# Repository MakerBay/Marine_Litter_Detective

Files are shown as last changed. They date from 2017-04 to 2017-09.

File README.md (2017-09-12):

# [Marine Litter Detective](http://marinelitterdetective.net/)

[Webpage Active now!](http://marinelitterdetective.net/)

http://marinelitterdetective.net/

Do you know where marine litter comes from?  A lot of litter generated on land actually ends up in the ocean, but how? WWF-Hong Kong, in cooperation with MakerBay, has designed a tracking device to simulate how litter enters the sea through storm drains and rivers, and is working with students from 11 schools to trace the journey of litter. This helps us understand the source of marine litter in Hong Kong and solve the problem together. If you find this device washed onto the shore, please pick it up and contact WWF (pyeung@wwf.org.hk) for collection. This project is sponsored by the Environment and Conservation Fund and the Environmental Campaign Committee of Hong Kong SAR Government.

wwf-logo-coconut

## Goal
Arduino in coconut
Map of Drifter in HK Waters

The goal of the Marine Litter Detective is to deploy more than a 100 GPS tracker devices to:
- Simulate the movement of trash from the land, into the drain system, into the river system, and into the sea of Hong Kong waters
- Create a map of coastal marine litter, to indicate where the trash comes from, where it goes, how quickly it travels, how frequently the same trash is observed on different beaches, how much of the trash goes in the ocean / gets stranded on the beach and more data
- Improve ocean current simulations and computer models
- Open hardware and software to enable more costal research and marine litter in the future

Our priorities are to make
- <b>reliable</b> GPS tracker fleets that give us frequent updates
- <b>environmentally friendly</b> casing (biodegradable)
- <b>low cost</b> 2G connected devices to operate in mobile phone range (good for coastal waters)
- devices which are <b>simple</b> to build so that over a hundred of students can build and deploy these sensors, collect data, analyse and share their findings

<hr>

## [Data visualisation](https://github.com/MakerBay/Trashtracker/tree/master/Dataviz)
Student Drifters

We have been very impressed with the work of Student Drifters, a research based program and we are learning a lot from them, principally about from their
- Python scripts and
- Leaflet-powered data visualisation: studentdrifters.org/huanxin/leaflet/examples/drifter.html .
We are  in the process of setting up a collaboration.

## [Software server side](https://github.com/MakerBay/Trashtracker/tree/master/Server)
Server

We are using a simple MySQL Server to collect the data via ftp/http request.
We are currently using a PHP script to extract the data and prepare it for data visualisation via a Json, or CSV file.

## [Software on device](https://github.com/MakerBay/Trashtracker/tree/master/Tracker)
Device

On the device we are using the Arduino IDE: https://www.arduino.cc/en/main/software

## [Electronics](https://github.com/MakerBay/Trashtracker/tree/master/Electronics)
Electonics

The devices are equipped with a 3.3V Arduino Pro Mini

## [Casing](https://github.com/MakerBay/Trashtracker/tree/master/Coconut)

We are trying to get our electronics as "eco" as possible, so the housing of our electronics is mainly composed of
- Wax / Paraffin: to make the electronics fully waterproof and float
- Tissue paper: to enhance the wax structure with the fibres to make it stronger

<hr>

## Credits
- [WWF-Hong Kong](https://wwf.org.hk)
- [MakerBay](https://www.makerbay.org)

## Team
- Patrick Yeung [WWF] +852 2161 9698, pyeung@wwf.org.hk
- Cesar Jung-Harada [MakerBay] +852 9610 7593, contact@cesarharada.com, https://github.com/cesarharada
- Eddie Yung [MakerBay] eddieyung2006@gmail.com, https://github.com/fisher4668
- Rohak Singhal [MakerBay] rohaksinghal14@gmail.com, https://github.com/krohak
- Jackie Wong Ching Sun [MakerBay] chinsun91@gmail.com, https://github.com/chinsun
- Michael CY CHENG [INDEPENDENT]

Special thanks to
- [Seeed Studio]( https://www.seeedstudio.com )
- [Student Drifter]( http://www.studentdrifters.org )
- Prof James Manning (NOAA) ( https://www.researchgate.net/profile/James_Manning3 )
- Xavier Huanxin Xu (NOAA)
- Tom Chi ( http://www.tomchi.com/ )
- Jie Qi (MIT) ( http://technolojie.com/category/featured-projects/ )
- Cy Keener (Stanford University) ( http://www.cykeener.com/ )
- Inspiration from https://www.greenwaveinstruments.com/product

<hr>

## Locations of launch
Classes Locations

11 Schools in Hong Kong all over the territory to launch at rivers and drains in 11 different areas
Totally 110 Devices will be deployed (10 devices per schools, 1 device per 2 to 3 students)

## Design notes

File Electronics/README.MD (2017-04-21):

# Bill of Materials
| Component | Quantity | Link |
| --- | --- | --- |
| Arduino Pro Mini 3.3V | 1 | https://goo.gl/s1k4pC |
| LoNet 808 Seeed (incl. GPS + Phone antenna) | 1 | https://goo.gl/HKax1F |
| Adapter board (custom made) | 1 | 
| Battery 18650 (2900mAh) | 1 | https://goo.gl/kCkjYg |
| Local Mobile SIM card | 1 | |
| Battery Wires, 15cm red and black | 1 | |
| Coconut shell from drinks | 1 | |
| Wax for Insulating electronics | 1 | |
| Cork chips | 1 | |
| Rubber Band from bicycle tyres | 1 | |
| "Dog Tag" in Aluminium with serial number and details to return device | 1 | https://goo.gl/YjCnZq |

This is how the different boards look like front and back

Gerber file Gerber file Gerber file Gerber file Gerber file

## Comments for manufacturing the kit with Seeed Studio
### LoNet 808
- LoNET 808 should come come with GPS and Phone antenna, does it?
- Header connector pins should be attached, can it be?
- LoNET 808 Power LED can be low power / skipped as it drains battery

Gerber file
### Comments for manufacturing PCBs
- PCBs to soldered
- PCBs to be Eco / Recycled PCBs / wood PCB

### Comments for sourcing batteries
- Battery 3000 mA/h, type: 18650, ideally Panasonic and cheap
- Can you make sure the batteries are 100% charged?
- Solder wires to the batteries (15cm) with connector mounted

### Comments for sourcing battery charger
- We need to charge 110 devices over 11 events. If we can charge 6 batteries at the time: great.

## Ask about
- Availabilites?
- Timeline?
- Bulk pricing?
- Overall budget?

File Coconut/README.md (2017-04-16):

# Find the coconut
supermarket coconut

# Drink the water
drink

# Cut it up
cut

# Eat the flesh
eat

# Chisel
chisel

# Prepare the electronics
elec

# Seal it
seal

# Launch the sensor
Launch the sensor

# Track your sensor
Track your sensor

# Research Notes 
## Biodegradable composite for casing
Biodegradable Material
Biodegradable Material
Moulded

In the process of developing the waterproofing of the electronics 

## Biodegradable electronics with paper and copper adhesive
Moulded

Above image is the courtesy of Jie Qi: https://www.flickr.com/photos/jieq/

Inspired by the work of Jie Qi we explored the possibility of making our own custom PCB out of paper and sticky copper. 
We hope to implement such eco-PCB soon. More research and tests coming soon :)

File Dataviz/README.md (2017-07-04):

This is the folder for Data Visualization

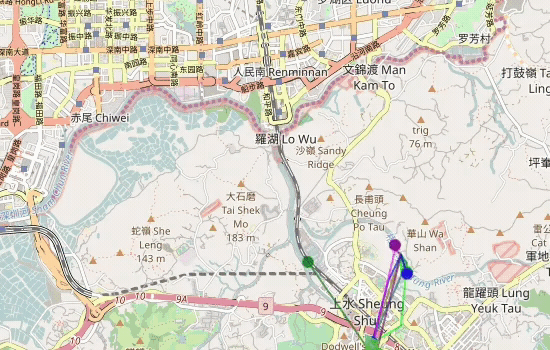
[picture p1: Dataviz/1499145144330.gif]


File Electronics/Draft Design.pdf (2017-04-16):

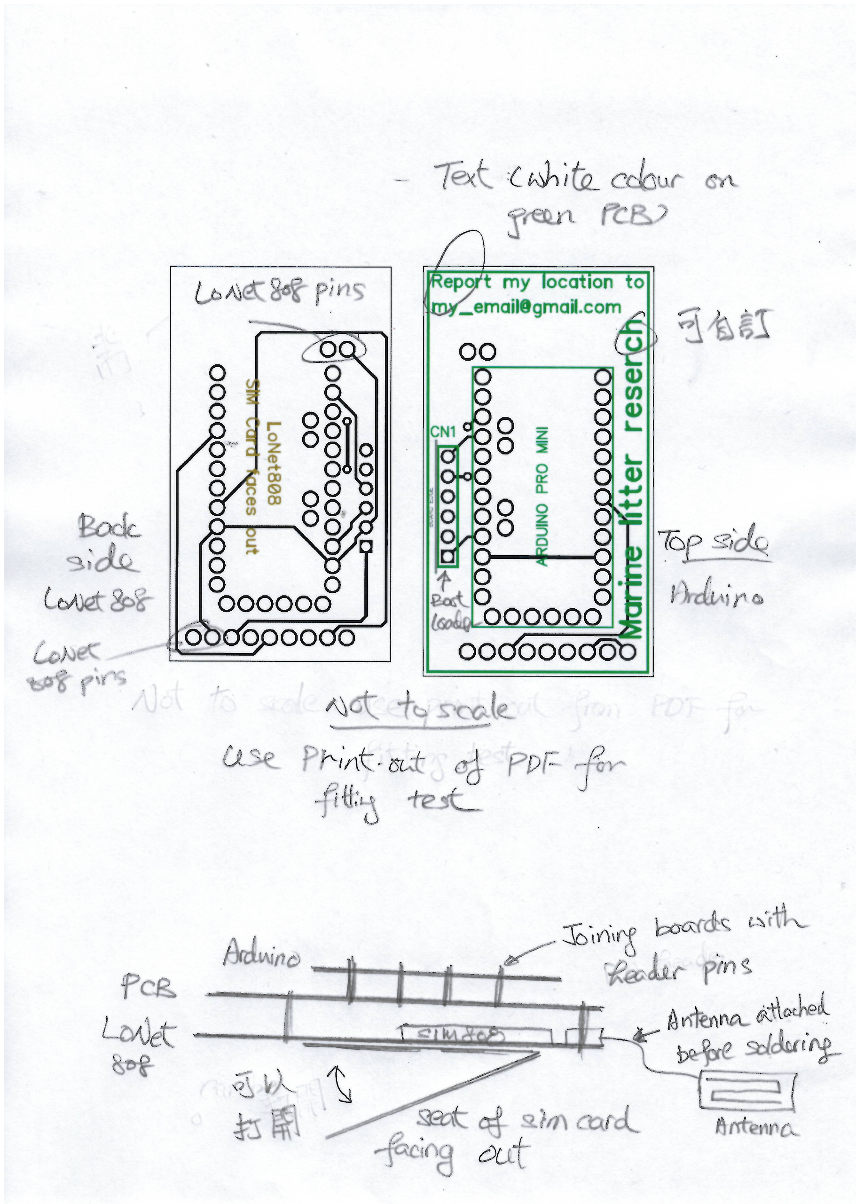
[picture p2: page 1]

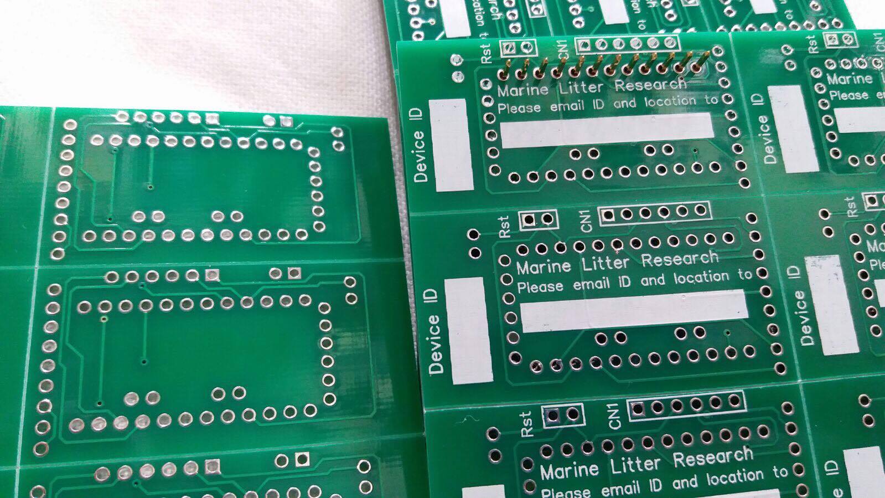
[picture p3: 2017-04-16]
Electronics/PCB boards ready to snap.jpg

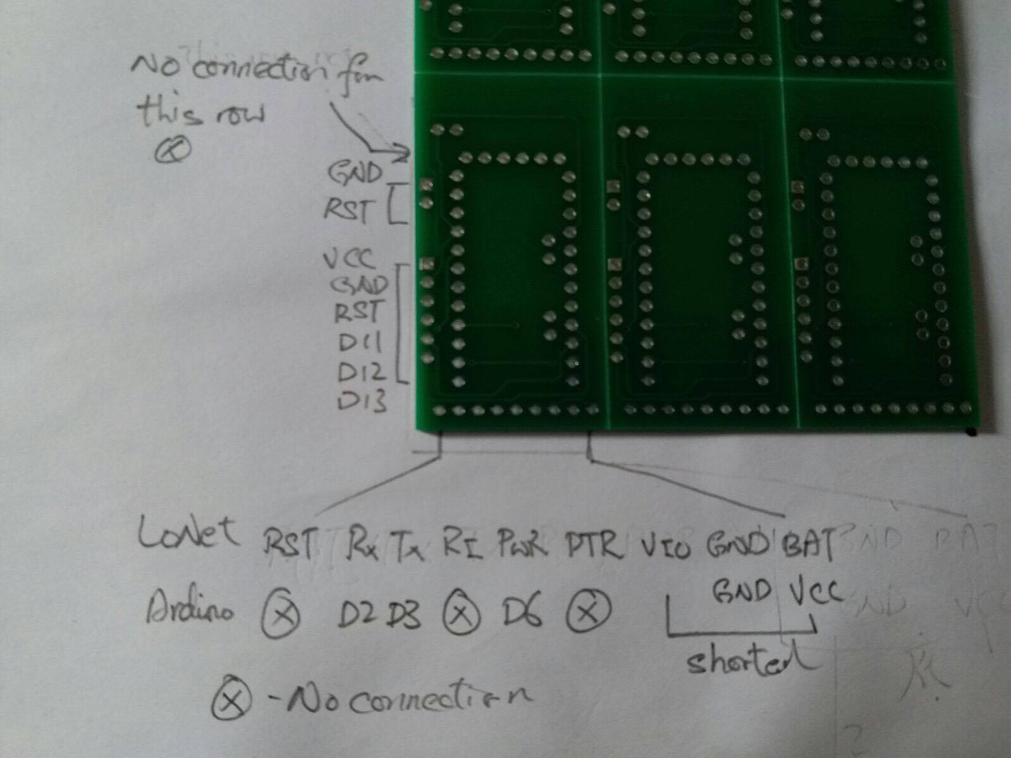
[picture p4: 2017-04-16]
Electronics/PCB photos with notes.jpg

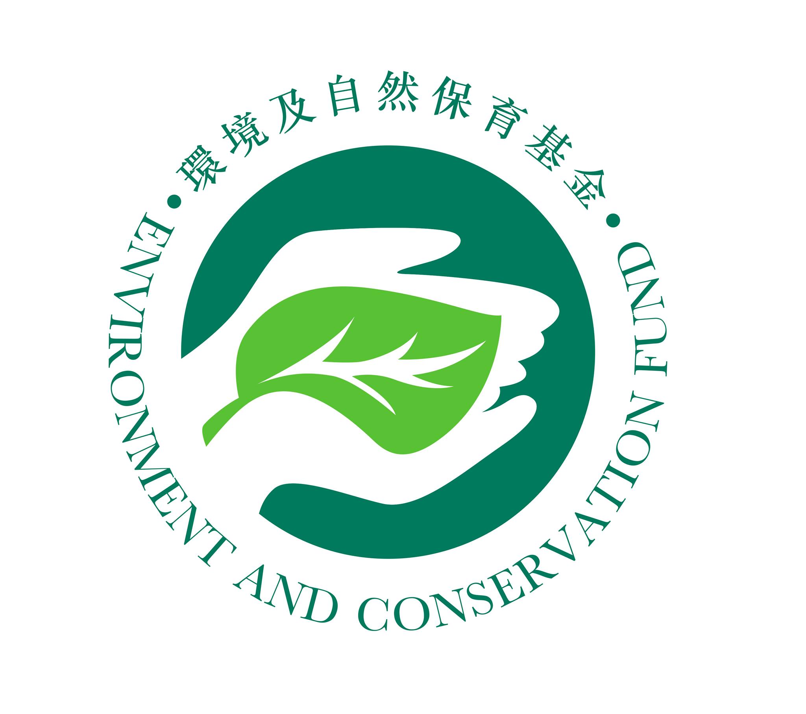
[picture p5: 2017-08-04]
Dataviz/img/leaf.jpg

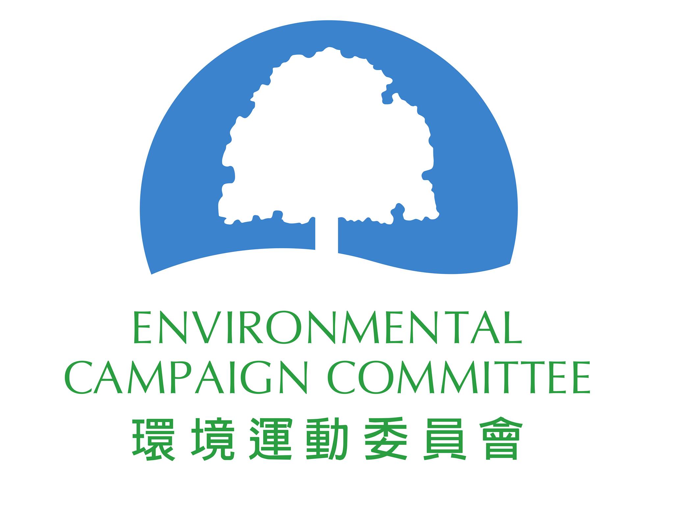
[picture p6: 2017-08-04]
Dataviz/img/tree.jpg

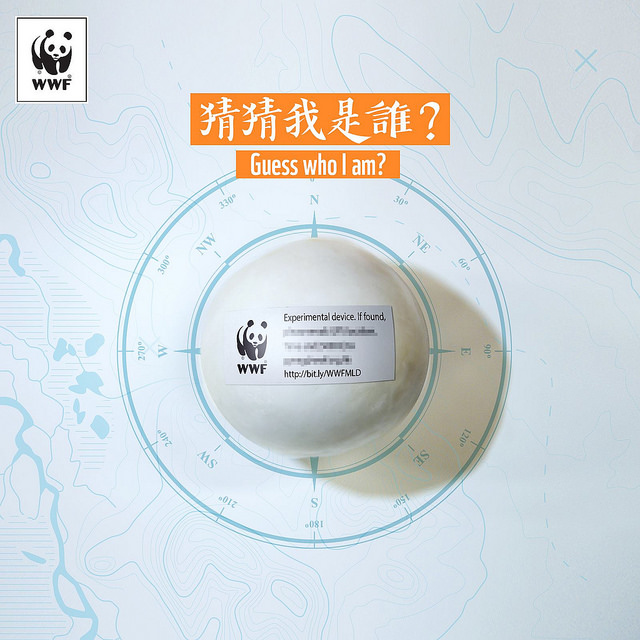
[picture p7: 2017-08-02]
Dataviz/img/drifter.jpg

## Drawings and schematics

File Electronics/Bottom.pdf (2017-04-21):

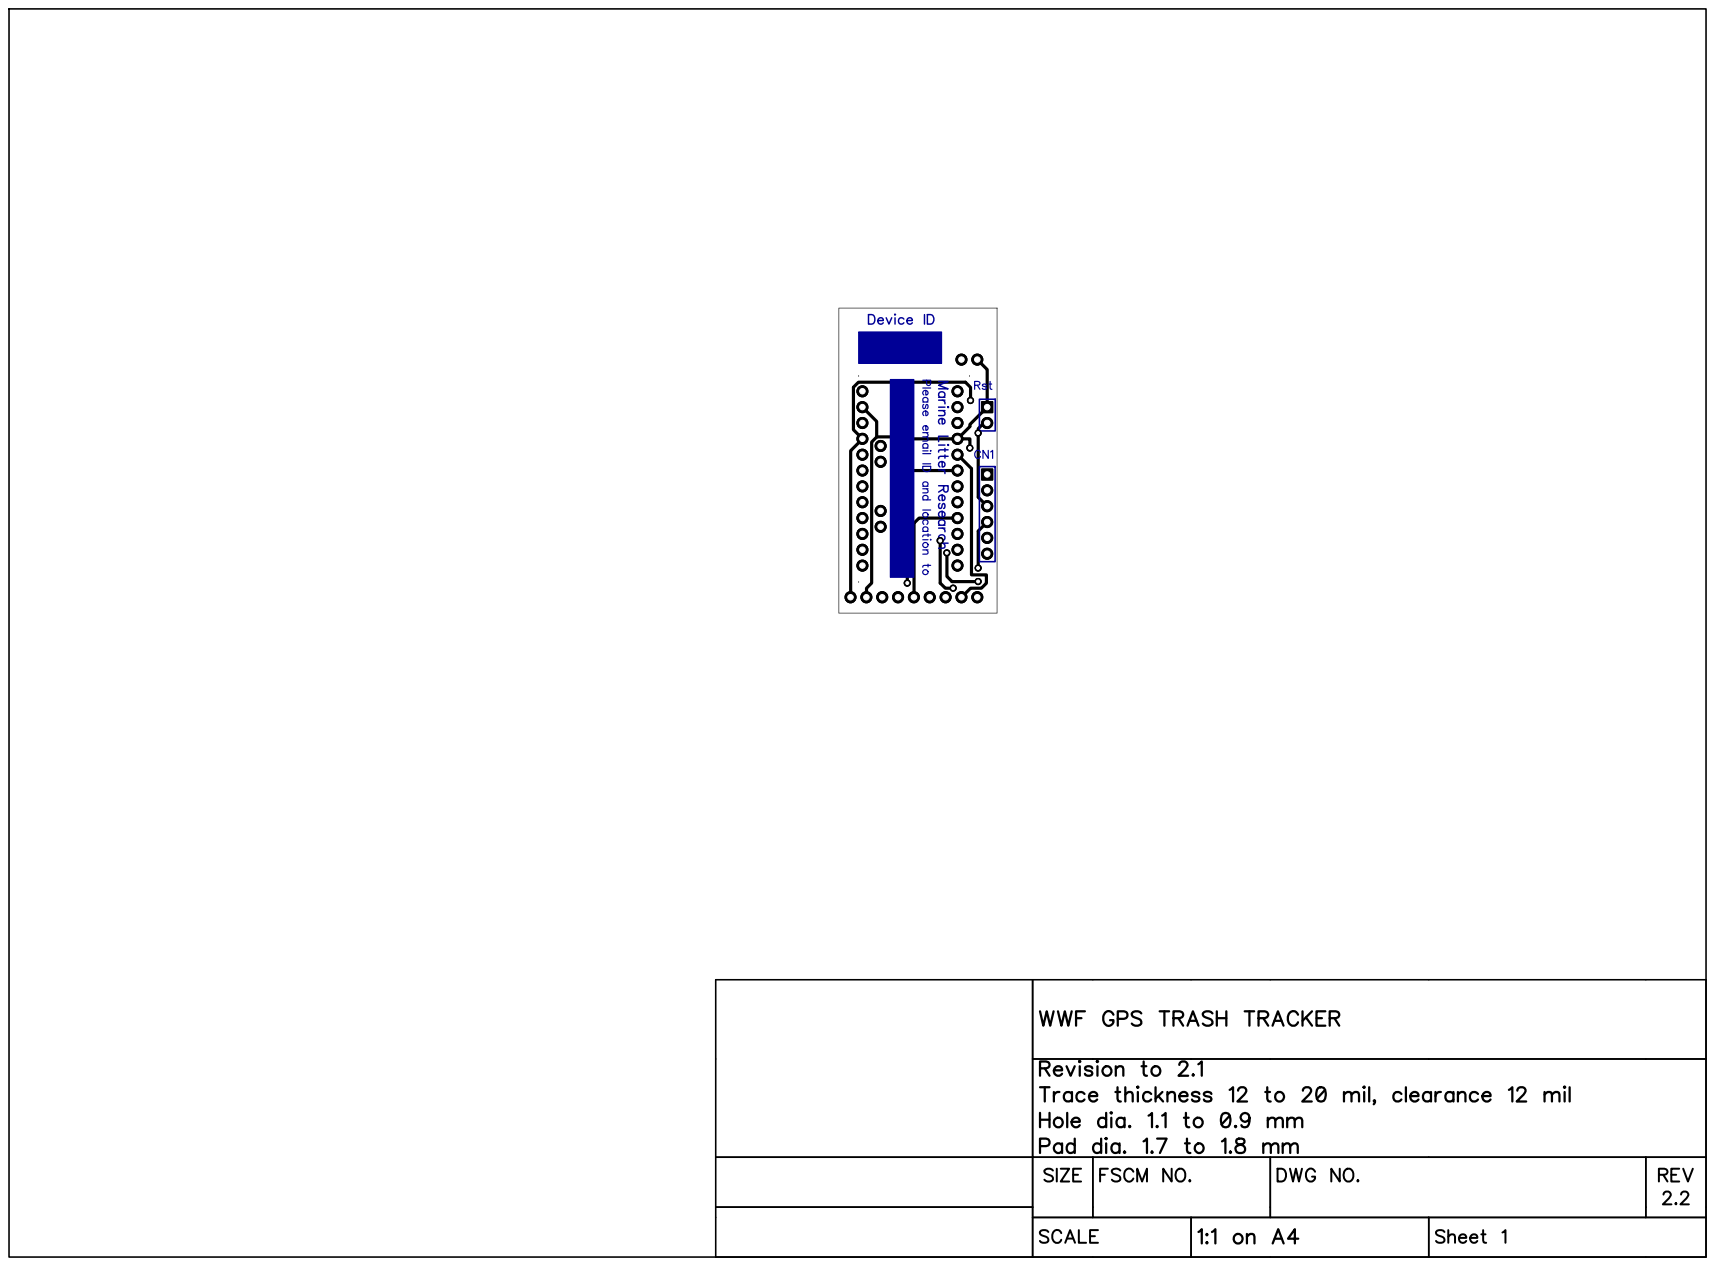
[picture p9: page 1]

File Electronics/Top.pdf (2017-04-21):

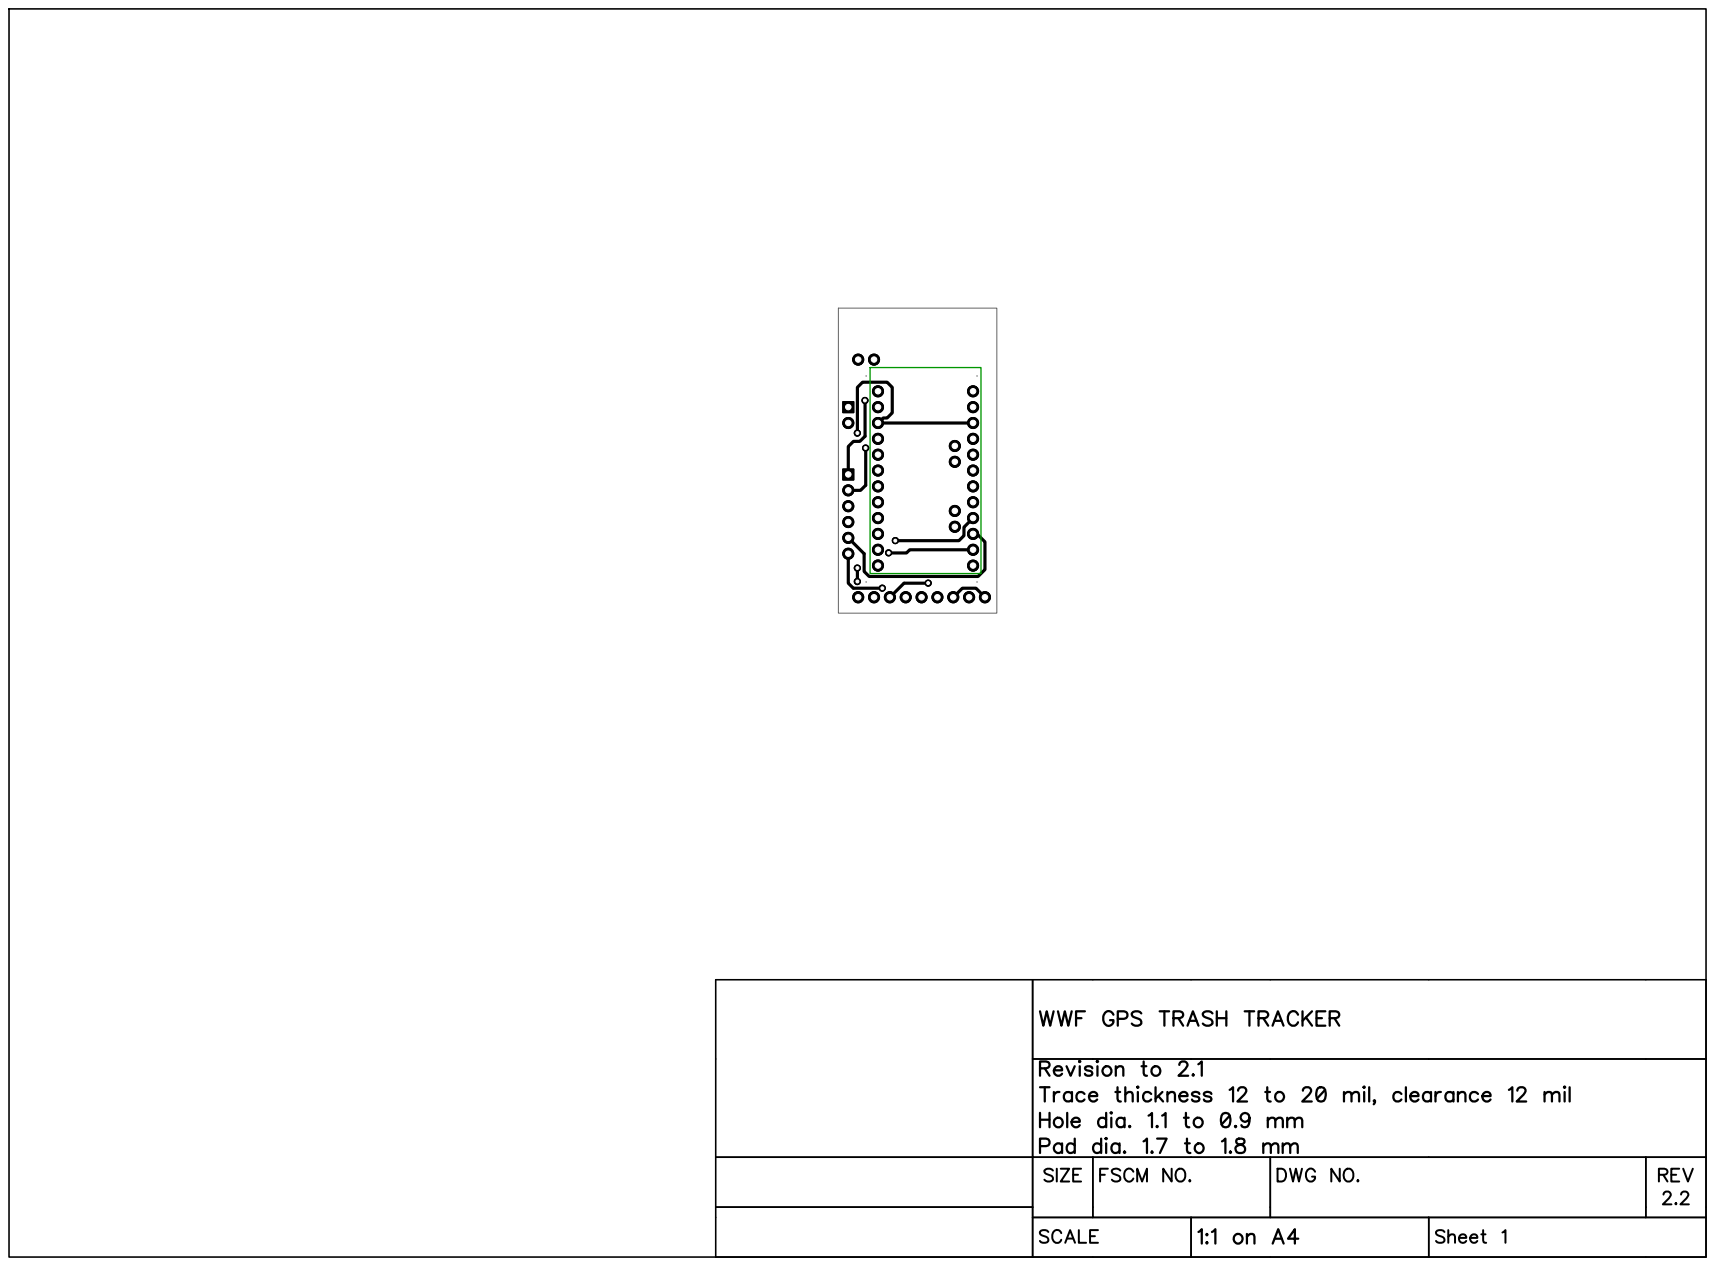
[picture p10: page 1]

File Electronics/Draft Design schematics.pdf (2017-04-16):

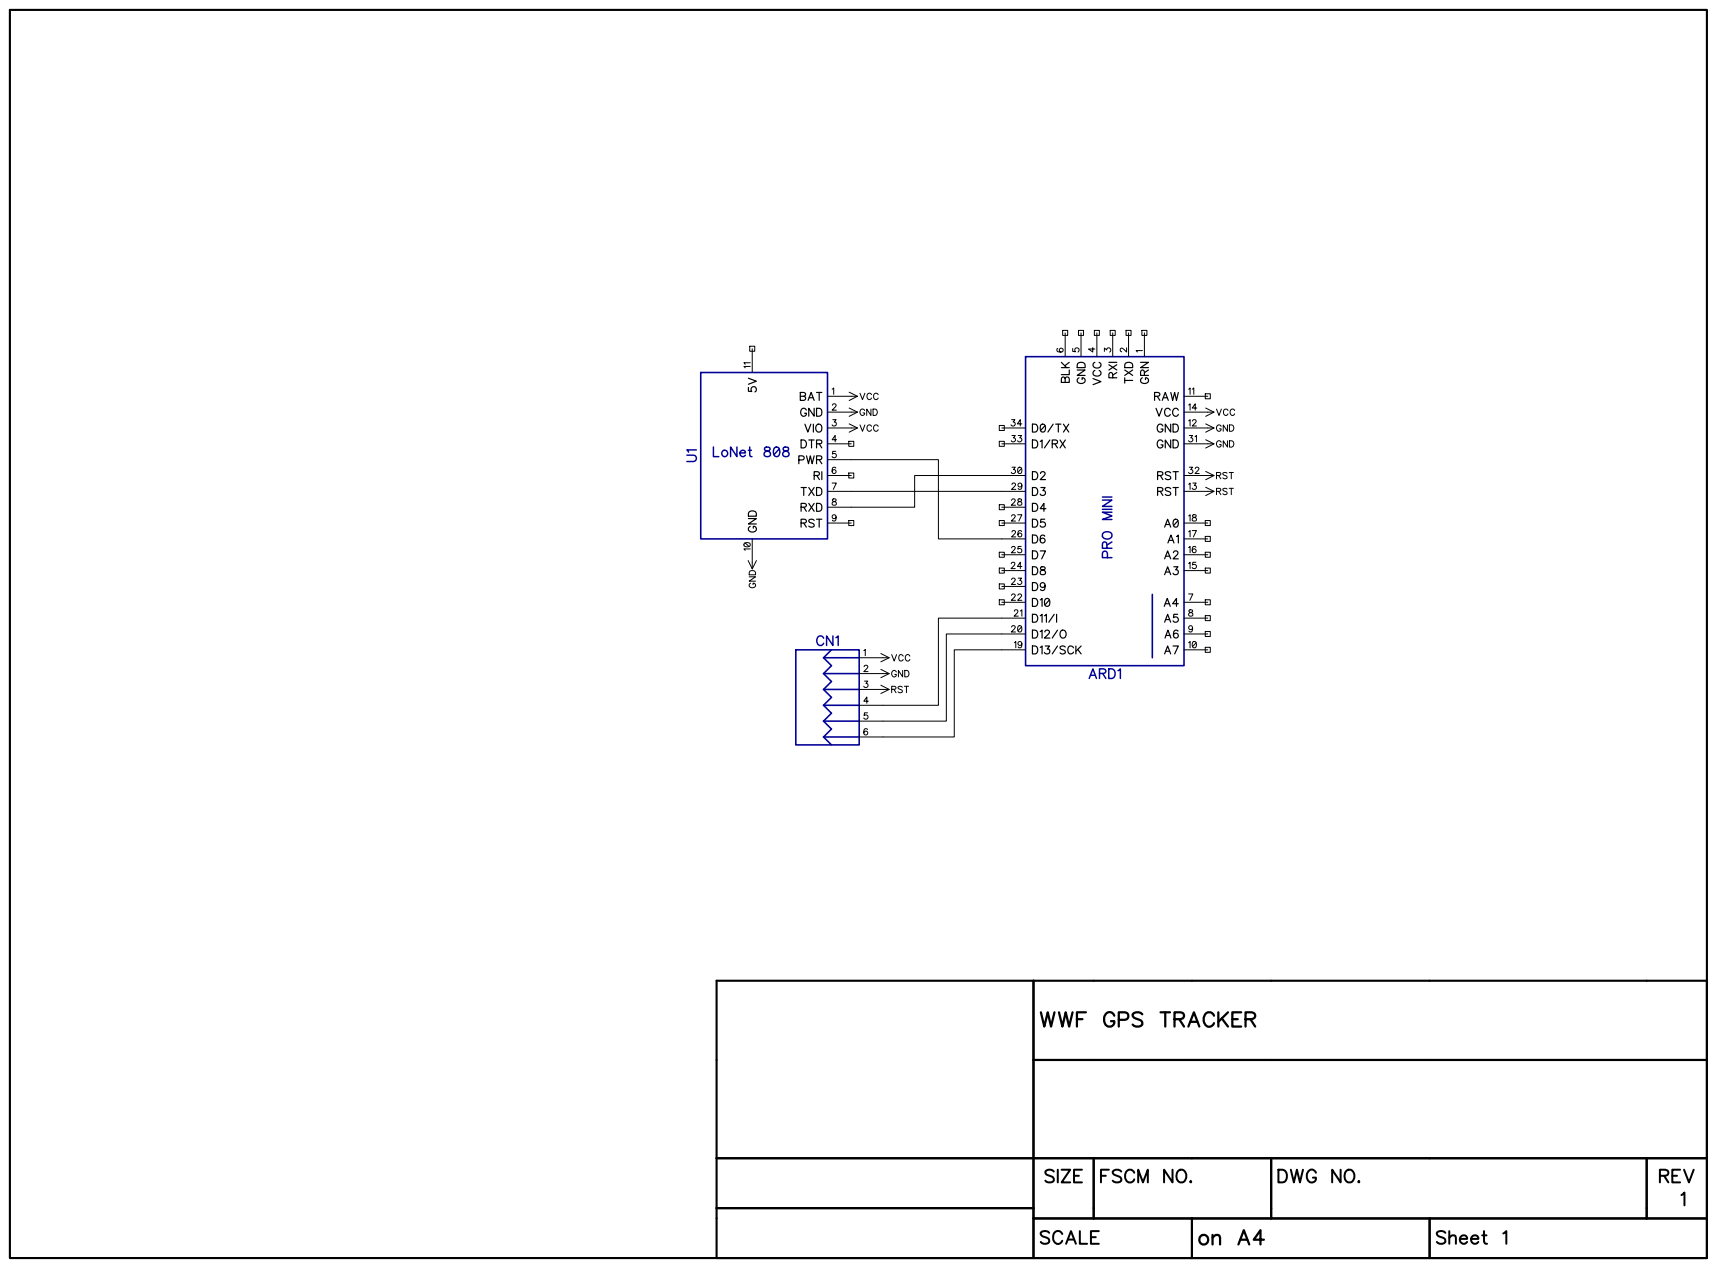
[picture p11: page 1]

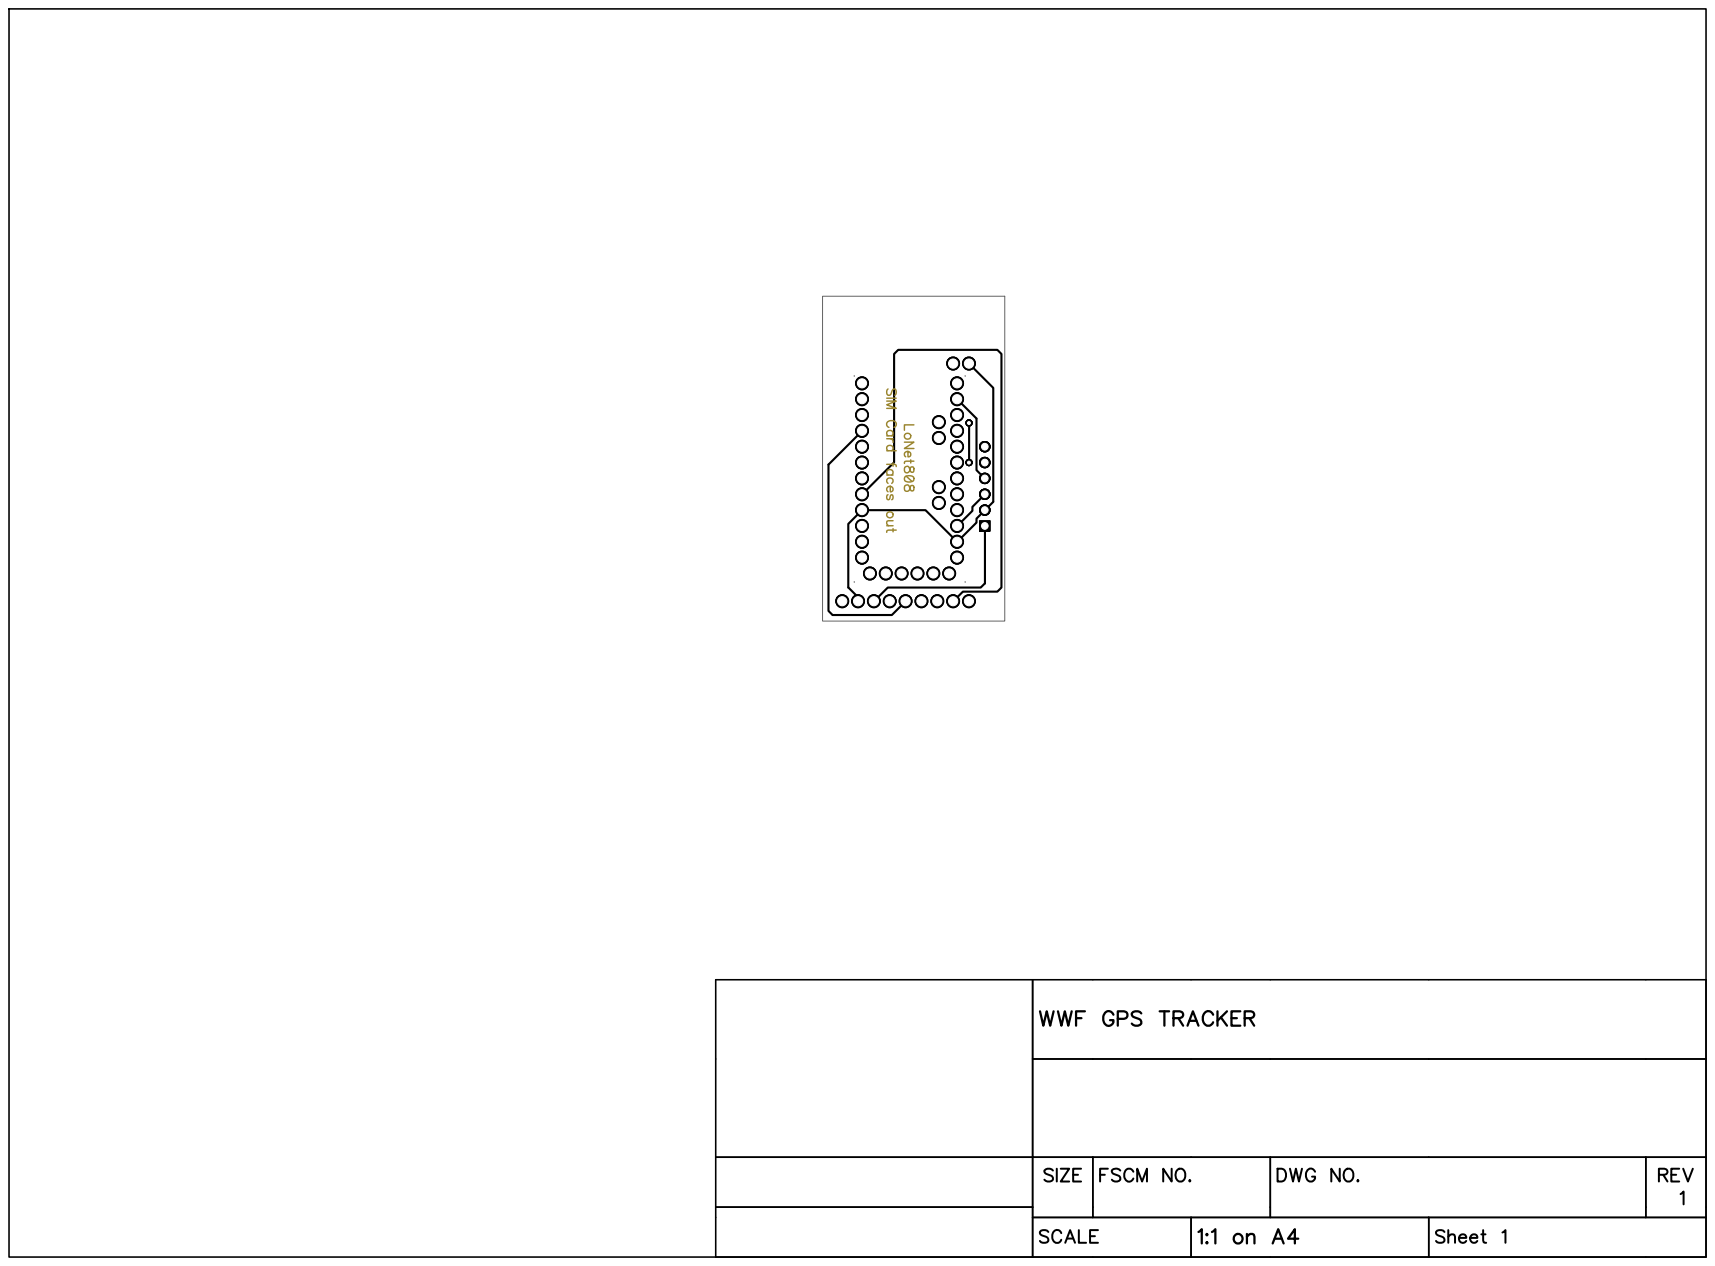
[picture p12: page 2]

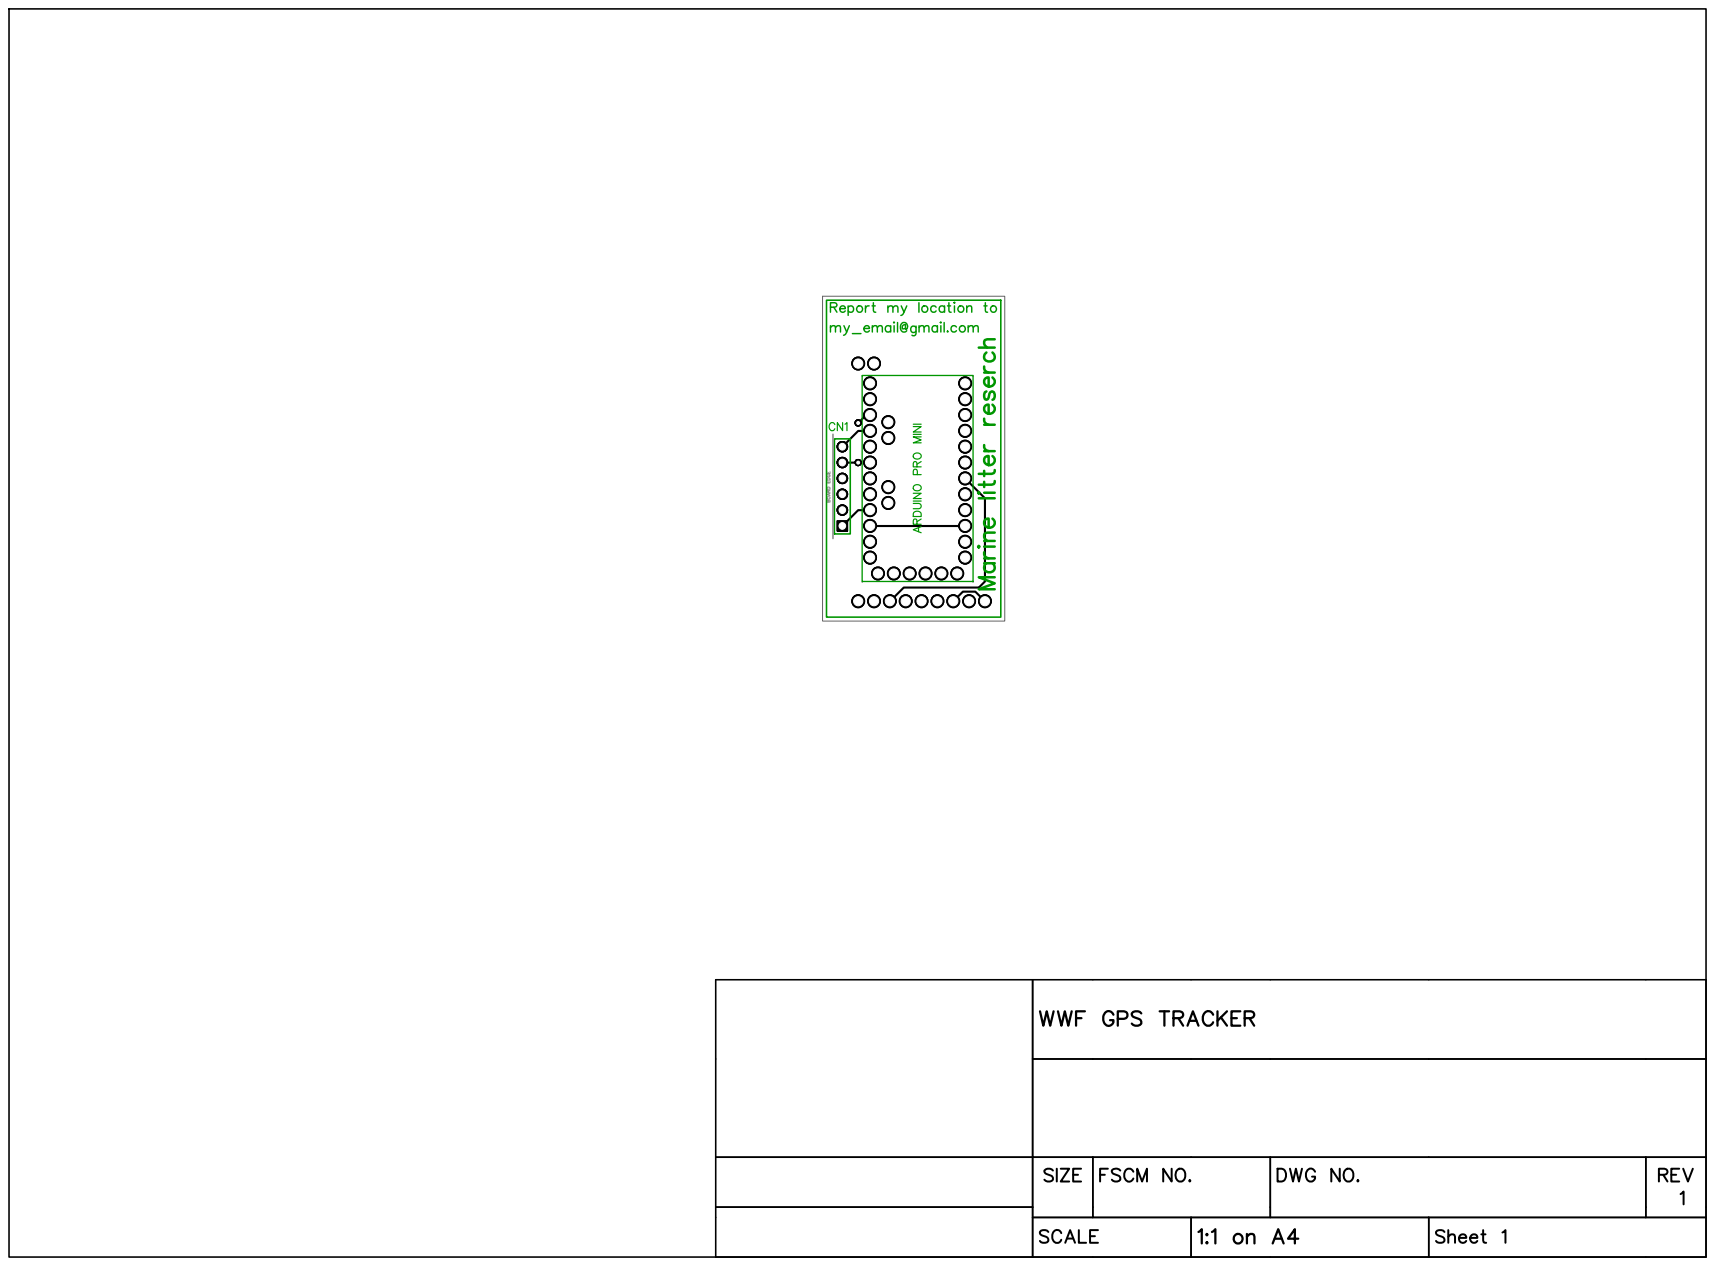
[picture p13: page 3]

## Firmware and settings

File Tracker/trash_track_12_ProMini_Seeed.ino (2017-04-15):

/***************************************************
  Adafruit IO FONA 808 GPS DEMO
  Designed specifically to work with the Adafruit FONA 808
  ----> https://www.adafruit.com/products/2542

  These cellular modules use TTL Serial to communicate, 2 pins are
  required to interface.

  Adafruit invests time and resources providing this open source code,
  please support Adafruit and open-source hardware by purchasing
  products from Adafruit!

  Written by Todd Treece for Adafruit Industries.
  MIT license, all text above must be included in any redistribution
 ****************************************************/

#include <SoftwareSerial.h>
#include "Adafruit_FONA.h"
#include "Adafruit_MQTT.h"
#include "Adafruit_MQTT_FONA.h"

#include "LowPower.h"
#include <avr/wdt.h>                  // add this for watchdog function

/*************************** Compile options ***********************************/

//#define _USE_TEST_PIN_  1
#define _OUTPUT_DEBUG_  1

/*************************** System definition ***********************************/
// One unique ID for each device
// 1xxx - Arduino UNO + Adafruit Fona 808
// 2xxx - Arduino UNO + Seeed (obsolete)
// 3xxx - Arduino Pro Mini + Seeed
//        3002 - sending to Adafruit IO
//        3012 - sending to Adafruit IO, mySQL
//        3022 - sending to Adafruit IO, mySQL and Thingspeak
// assign a new ID for each device to avoid messing up with existing data

// Custom info: it should be a 4-digit ID
#define PROJECT_DEVICE_ID xxxx

/*************************** FONA Pins and class init ***********************************/

#define FONA_RX     2
#define FONA_TX     3
#define FONA_RST    4

SoftwareSerial fonaSS = SoftwareSerial(FONA_TX, FONA_RX);

// GO! we define two pins for the same function
// Pin 8 is for use with UNO
// Pin 6 is for use with Pro Mini
// Status is skipped now

#define PIN_GSM_POWER 8
#define PIN_GSM_POWER_2 6
#define PIN_GSM_STATUS_POWER 7
#define PIN_ONBOARD_LED 13
#define PIN_TEST_01 A0

Adafruit_FONA fona = Adafruit_FONA(FONA_RST);

/*************************** Cellular APN *************************************/

  // Optionally configure a GPRS APN, username, and password.
  // You might need to do this to access your network's GPRS/data
  // network.  Contact your provider for the exact APN, username,
  // and password values.  Username and password are optional and
  // can be removed, but APN is required.
  // GO! for the China Motion SIM card... this is the settings

// Custom info: put in the carrier APN and password
#define FONA_APN       "CMHK"
#define FONA_USERNAME  ""
#define FONA_PASSWORD  ""

/************************* Adafruit.io Setup *********************************/
/* Use new feeds for new devices to avoid messing up with existing feeds     */
/*****************************************************************************/

#define AIO_SERVER      "io.adafruit.com"
#define AIO_SERVERPORT  1883
// Custom info: put in AIO username and AIO_KEY
#define AIO_USERNAME    "xxxxxxx"    // "...your AIO username (see https://accounts.adafruit.com)..."
#define AIO_KEY         "xxxxxxxxxxxxxxxxxxxxxxxxxxxxxxxx"

/************************* definitions for mySQL *********************************/

// Custom info: the link to the mySQL database via php, change the domain name as well
#define STRING_HTTP_LEADING "makerbench.org/xxxxxxxxxxxxxx.php?"

/************************* Thingspeak ****************************************/
/* Use new feeds for new devices to avoid messing up with existing feeds     */
/*****************************************************************************/

// Custom info: specify an API key to send to thingspeak
#define STRING_THINGSPEAK_LEADING "api.thingspeak.com/update?api_key=XXXXXXXXXXXXXXXX"

/************************* GPS *********************************/

#define GPS_NUM_ATTEMPTS        10
#define GPS_ATTEMPT_INTERVAL_MS  6000
int gpsAttemptCount;
int gpsCount;
boolean gps_success;

/************************* Sleep time management *********************************/

int sleepTime;
unsigned char smSlpTime = 0;

/************ Global State (you don't need to change this!) ******************/

// Store the MQTT server, client ID, username, and password in flash memory.
// This is required for using the Adafruit MQTT library.
// GO! do not use PROGMEM const char MQTT_SERVER[] PROGMEM    = AIO_SERVER;
// Set a unique MQTT client ID using the AIO key + the date and time the sketch
// was compiled (so this should be unique across multiple devices for a user,
// alternatively you can manually set this to a GUID or other random value).
const char MQTT_CLIENTID[] PROGMEM  = __TIME__ AIO_USERNAME;
// GO! do not use PROGMEM const char MQTT_USERNAME[] PROGMEM  = AIO_USERNAME;
// GO! do not use PROGMEM const char MQTT_PASSWORD[] PROGMEM  = AIO_KEY;

// Setup the FONA MQTT class by passing in the FONA class and MQTT server and login details.
Adafruit_MQTT_FONA mqtt(&fona, AIO_SERVER, AIO_SERVERPORT, AIO_USERNAME, AIO_KEY);
// GO! do not use PROGMEM Adafruit_MQTT_FONA mqtt(&fona, MQTT_SERVER, AIO_SERVERPORT, MQTT_CLIENTID, MQTT_USERNAME, MQTT_PASSWORD);

// You don't need to change anything below this line!
// shortened to 100ms now
//#define halt(s) { Watchdog.enable(100); Serial.println(F( s )); while(1) digitalWrite(PIN_TEST_01,!digitalRead(PIN_TEST_01));  }
#define halt(s) { wdt_enable(WDTO_250MS); Serial.println(F( s )); while(1); }

// FONAconnect is a helper function that sets up the FONA and connects to
// the GPRS network. See the fonahelper.cpp tab above for the source!
boolean FONAconnect(const __FlashStringHelper *apn, const __FlashStringHelper *username, const __FlashStringHelper *password);

/****************************** Feeds ***************************************/

// examples from Geofence
//Adafruit_MQTT_Publish location_feed = Adafruit_MQTT_Publish(&mqtt, AIO_USERNAME "/feeds/" LOCATION_FEED_NAME "/csv");
//Adafruit_MQTT_Publish battery_feed = Adafruit_MQTT_Publish(&mqtt, AIO_USERNAME "/feeds/battery");
//Adafruit_MQTT_Publish alerts_feed = Adafruit_MQTT_Publish(&mqtt, AIO_USERNAME "/feeds/alerts");

// original for gps
// Notice MQTT paths for AIO follow the form: <username>/feeds/<feedname>/csv
//const char GSMLOC_FEED[] PROGMEM = AIO_USERNAME "/feeds/gsmloc/csv";
//Adafruit_MQTT_Publish gsmloc = Adafruit_MQTT_Publish(&mqtt, GSMLOC_FEED);
//const char GPSLOC_FEED[] PROGMEM = AIO_USERNAME "/feeds/gps/csv";
//Adafruit_MQTT_Publish gpsloc = Adafruit_MQTT_Publish(&mqtt, GPSLOC_FEED);

// GO! combine the two and make these
Adafruit_MQTT_Publish gsmloc = Adafruit_MQTT_Publish(&mqtt, AIO_USERNAME "/feeds/gsm3022/csv");
Adafruit_MQTT_Publish gpsloc = Adafruit_MQTT_Publish(&mqtt, AIO_USERNAME "/feeds/gps3022/csv");
Adafruit_MQTT_Publish batlevel = Adafruit_MQTT_Publish(&mqtt, AIO_USERNAME "/feeds/battery3022");   // omit the /csv

char gpsbuffer[160];

/*************************** Sketch Code ************************************/

// How many transmission failures in a row we're willing to be ok with before reset
uint8_t txfailures = 0;
#define MAXTXFAILURES 3

void setup() {

  digitalWrite(PIN_GSM_POWER, HIGH);  // set to high
  digitalWrite(PIN_GSM_POWER_2, HIGH);  // set to high
  pinMode(PIN_GSM_POWER, OUTPUT);     // ensure output mode for GSM power pin
  pinMode(PIN_GSM_POWER_2, OUTPUT);     // ensure output mode for GSM power pin
  pinMode(PIN_GSM_STATUS_POWER, INPUT); // read GSM module power status
  pinMode(PIN_ONBOARD_LED, OUTPUT);   // just to make sure this LED remains OFF
  digitalWrite(PIN_ONBOARD_LED, LOW); // ensure the D13 LED won't turn on so as to conserve power

#if defined(_USE_TEST_PIN_)
  pinMode(PIN_TEST_01, OUTPUT);
  digitalWrite(PIN_TEST_01, LOW);   // test pin set to low at reset
#endif

  while (!Serial);
  Serial.begin(115200);

  Serial.println(F("Green Orange: GPS tracker System"));
  Serial.println(F("Power ON GSM system"));

  // do a negative pulse to turn ON GSM if GSM is currently off
  // the exit condition is that the power status pin goes high
  // if for some reasons the Fona fails to be turned on, the Arduino never stop
  
//  if (!digitalRead(PIN_GSM_STATUS_POWER))
//    {
    digitalWrite(PIN_GSM_POWER, LOW);  // set to low
    digitalWrite(PIN_GSM_POWER_2, LOW);  // set to low
    delay(1300);                         // spec requirement is 1 sec
    digitalWrite(PIN_GSM_POWER, HIGH);  // set to high
    digitalWrite(PIN_GSM_POWER_2, HIGH);  // set to high
    // should have turned ON, delay for module stability - delay time still to be finalized
    // wdt_reset();
    delay(5000);      // before it was 5000, think no need that long - hmmm.  wondering if 2000 would cause any problem. let's keep it 5000
//    }
    //wdt_reset();

  // attempt to get in touch with Fona on serial port
  // watchdog is enabled only inside the below
  // if done properly, the below is confirmed
  // - Fona is talking via UART
  // - Fona is registered to a network - 2G (if no 2G available this is not a pass here)
  // - GPRS is enabled also

  if (! FONAconnect(F(FONA_APN), F(FONA_USERNAME), F(FONA_PASSWORD)))
    {
    //halt("Retrying FONA");
    restIdle();                     // now instead of halting for a reset immediately, we rest for idle
    }
    
  Serial.println(F("Connected to Cellular!"));

  fona.enableGPS(true);

  wdt_reset();
  delay(3000);  // wait a few seconds to stabilize connection
  wdt_reset();

  // connect to adafruit io
  connect();
  sleepTime = 0;
}

uint32_t x=0;

void loop() {

  char sendbuffer[120];
          uint16_t statuscode;
          int16_t length;
          char url[160];

  // Make sure to reset watchdog every loop iteration!
  wdt_reset();

  // ping adafruit io a few times to make sure we remain connected
  if(! mqtt.ping(3)) {
    // reconnect to adafruit io
    if(! mqtt.connected())
      connect();
  }

  float latitude, longitude, speed_kph, heading, speed_mph, altitude;
  float gpsLatitude, gpsLongitude;
  
  // if you ask for an altitude reading, getGPS will return false if there isn't a 3D fix
  // GO! it takes time for the GPS to get a fix after power-cycle so we need to attempt multiple times

  gpsAttemptCount = 0;
  while (gpsAttemptCount < GPS_NUM_ATTEMPTS)
  {
  gps_success = fona.getGPS(&latitude, &longitude, &speed_kph, &heading, &altitude);
  gpsLatitude = latitude;
  gpsLongitude = longitude;
  
  if (gps_success && !(longitude == 0 || altitude ==0 )) {

    gpsCount = gpsAttemptCount + 1;
    gpsAttemptCount = GPS_NUM_ATTEMPTS + 8;       // confirms that we don't need to do it again
    fona.enableGPS(false);    // no need to keep GPS on when sending data to cloud

#if defined(_OUTPUT_DEBUG_)
    Serial.print("GPS lat:");
    Serial.println(latitude);
    Serial.print("GPS long:");
    Serial.println(longitude);
    Serial.print("GPS speed KPH:");
    Serial.println(speed_kph);
    Serial.print("GPS speed MPH:");
    speed_mph = speed_kph * 0.621371192;
    Serial.println(speed_mph);
    Serial.print("GPS heading:");
    Serial.println(heading);
    Serial.print("GPS altitude:");
    Serial.println(altitude);
#endif

    // snprintf(sendbuffer, 120, "%d,%f,%f,0", x, latitude, longitude);
    // but that doesnt work in arduino
    char *p = sendbuffer;
    // add speed value
    // GO! borrow the value of speed_mph as private ID value
    speed_mph = PROJECT_DEVICE_ID;
    dtostrf(speed_mph, 4, 0, p);
    p += strlen(p);
    p[0] = ','; p++;
    // concat latitude
    dtostrf(latitude, 2, 6, p);
    p += strlen(p);
    p[0] = ','; p++;
    // concat longitude
    dtostrf(longitude, 3, 6, p);
    p += strlen(p);
    p[0] = ','; p++;
    // concat altitude
    dtostrf(altitude, 2, 6, p);
    p += strlen(p);
    // null terminate
    p[0] = 0;

    Serial.print("Sending: "); Serial.println(sendbuffer);

    if (! gpsloc.publish(sendbuffer)) {
      Serial.println(F("Failed"));
      txfailures++;
    } else {
      Serial.println(F("OK!"));
      txfailures = 0;
    }
    wdt_reset();
  }
  else
      {
        wdt_reset();
        delay(GPS_ATTEMPT_INTERVAL_MS);
        wdt_reset();
        gpsAttemptCount++;
        }
  } // ending while loop
  fona.enableGPS(false);
  
        uint16_t vbat;
        if (! fona.getBattVoltage(&vbat)) {
          Serial.println(F("Failed to read Batt"));
        } else {
          Serial.print(F("VBat = ")); Serial.print(vbat); Serial.println(F(" mV"));
          char *p = sendbuffer;
          // add voltage value
          dtostrf(vbat, 2, 1, p);
          p += strlen(p);
          // null terminate
          p[0] = 0;
          if (! batlevel.publish(sendbuffer)) {
              Serial.println(F("Failed"));
              txfailures++;
          } else {
              Serial.println(F("OK! voltage sent"));
              txfailures = 0;
                }
          wdt_reset();
        }

  boolean gsmloc_success = fona.getGSMLoc(&latitude, &longitude);

  if (gsmloc_success) {

    Serial.print("GSMLoc lat:");
    Serial.println(latitude);
    Serial.print("GSMLoc long:");
    Serial.println(longitude);

    // snprintf(sendbuffer, 120, "%d,%f,%f,0", x, latitude, longitude);
    // but that doesnt work in arduino
    char *p;

    // paste in 'value' first, just an incrementer for GSMLoc
    itoa(x, sendbuffer, 10);
    p = sendbuffer+strlen(sendbuffer);
    p[0] = ','; p++;
    // concat latitude
    dtostrf(latitude, 2, 6, p);
    p += strlen(p);
    p[0] = ','; p++;
    // concat longitude
    dtostrf(longitude, 3, 6, p);
    p += strlen(p);
    p[0] = ','; p++;
    p[0] = '0'; p++;  // 0 altitude
    // null terminate
    p[0] = 0;

  if (gpsAttemptCount != (GPS_NUM_ATTEMPTS + 8))    // if GPS has been sent, we don't send GSM
  {
    Serial.print("Sending: "); Serial.println(sendbuffer);
    if (! gsmloc.publish(sendbuffer)) {
      Serial.println(F("Failed"));
      txfailures++;
    } else {
      Serial.println(F("OK!"));
      txfailures = 0;
    }
  }
  }

  wdt_reset();

  // GO! here the added portion to send the whole thing to mySQL

    char  *url_;
    url_ = url;
    // The leading string
    sprintf(url_, STRING_HTTP_LEADING);
    url_ += strlen(url_);
    // The ID
    sprintf(url_, "M_id=%d", PROJECT_DEVICE_ID);
    url_ += strlen(url_);
    // The battery level
    sprintf(url_, "&M_Batt=%4.0d", vbat);
    url_ += strlen(url_);
    // The latitude
    sprintf(url_, "&M_Lat=");                     //, gpsLatitude);
    url_ += strlen(url_);
    if (gpsLatitude > 1 && gpsLatitude < 99)
          {
          dtostrf(gpsLatitude, 2, 6, url_);
          url_ += strlen(url_);
          }
    // The longitude
    sprintf(url_, "&M_Long=");                    //, gpsLongitude);
    url_ += strlen(url_);
    if (gpsLongitude > 1 && gpsLongitude < 199)
        {
          dtostrf(gpsLongitude, 3, 6, url_);
          url_ += strlen(url_);
        }
    // The gsm latitude
    if (latitude == 0) latitude = 99;
    sprintf(url_, "&G_Lat=");                     //, latitude);
    url_ += strlen(url_);
    dtostrf(latitude, 2, 6, url_);
    url_ += strlen(url_);
    // The gsm longitude
    if (longitude == 0) longitude = 999;
    sprintf(url_, "&G_Long=");                    //, longitude);
    url_ += strlen(url_);
    dtostrf(longitude, 3, 6, url_);
    url_ += strlen(url_);
    // The GPS retrial record
    sprintf(url_, "&GPS_cnt=%d", gpsCount);
    url_ += strlen(url_);
    // null termination
    url_[0] = 0;
    //url[0] = ','; url++;

        // print out for testing
        
        Serial.println(url);
        wdt_reset();
        wdt_disable();
          if (!fona.HTTP_GET_start(url, &statuscode, (uint16_t *)&length)) {
          Serial.println("Failed!");
        }
        else  {
        while (length > 0) {
          while (fona.available()) {
            char c = fona.read();

            embeddedCmd(c);
            
            // Serial.write is too slow, we'll write directly to Serial register!
#if defined(__AVR_ATmega328P__) || defined(__AVR_ATmega168__)
            loop_until_bit_is_set(UCSR0A, UDRE0); /* Wait until data register empty. */
            UDR0 = c;
#else
            Serial.write(c);
#endif
            length--;
            wdt_reset();
            if (! length) break;
          }
        }
        }
        wdt_enable(WDTO_8S);

  x++;

  /* send to thingspeak */

    url_ = url;
    // The leading string
    sprintf(url_, STRING_THINGSPEAK_LEADING);
    url_ += strlen(url_);
    // The ID
    sprintf(url_, "&field1=%d", PROJECT_DEVICE_ID);
    url_ += strlen(url_);
    // The battery level
    sprintf(url_, "&field2=%4.0d", vbat);
    url_ += strlen(url_);
    // The latitude
    sprintf(url_, "&field3=");                     //, gpsLatitude);
    url_ += strlen(url_);
    if (gpsLatitude > 1 && gpsLatitude < 99)
          {
          dtostrf(gpsLatitude, 2, 6, url_);
          url_ += strlen(url_);
          }
    // The longitude
    sprintf(url_, "&field4=");                    //, gpsLongitude);
    url_ += strlen(url_);
    if (gpsLongitude > 1 && gpsLongitude < 199)
        {
          dtostrf(gpsLongitude, 3, 6, url_);
          url_ += strlen(url_);
        }
    // The gsm latitude
    if (latitude == 0) latitude = 99;
    sprintf(url_, "&field5=");                     //, latitude);
    url_ += strlen(url_);
    dtostrf(latitude, 2, 6, url_);
    url_ += strlen(url_);
    // The gsm longitude
    if (longitude == 0) longitude = 999;
    sprintf(url_, "&field6=");                    //, longitude);
    url_ += strlen(url_);
    dtostrf(longitude, 3, 6, url_);
    url_ += strlen(url_);
    // null termination
    url_[0] = 0;
    //url[0] = ','; url++;

            Serial.println(url);
            wdt_reset();
            wdt_disable();
            if (!fona.HTTP_GET_start(url, &statuscode, (uint16_t *)&length)) 
              {
              Serial.println(F("Get Failed!"));
              } 
           fona.HTTP_GET_end();  
        wdt_enable(WDTO_8S);
        Serial.println(F("\n****"));
        fona.HTTP_GET_end();

  // wait a couple seconds before starting over
  wdt_reset();
  delay(2000);
  wdt_reset();
  // everything done successfully, rest idle before resetting for the next round
  restIdle();
}

void restIdle(void)
{
int ii,jj;
int sleepMS;

// do a negative pulse to turn OFF GSM
//  if (digitalRead(PIN_GSM_STATUS_POWER))
//    {
    Serial.println(F("Turn off GSM..."));
    digitalWrite(PIN_GSM_POWER, LOW);  // set to low
    digitalWrite(PIN_GSM_POWER_2, LOW);  // set to low
    delay(1300);                         // spec requirement is 1 sec
    digitalWrite(PIN_GSM_POWER, HIGH);  // set to low
    digitalWrite(PIN_GSM_POWER_2, HIGH);  // set to low
//    }
  // wait for 15 minutes or whatever, during this time, Arduino should be sleep also

  wdt_reset();
  Serial.println(F("System Hibernates"));

  delay(500);                 // delay for printing
  wdt_disable();
  if (sleepTime <= 10)
    sleepTime = 10;
  if (sleepTime >= 60)
    sleepTime = 60;
  Serial.print(sleepTime);
  Serial.println(F(" minutes"));
  delay(500);
  for (jj=0; jj<sleepTime; jj++)     // this is roughly a minute count
  for (ii=0; ii<8; ii++)                // wait for 8x8=64 seconds (measured to be 68 seconds?) - say it is a minute
    LowPower.powerDown(SLEEP_8S, ADC_OFF, BOD_OFF);  
  halt("System restart!");
  }

// connect to adafruit io via MQTT
void connect() {

  // check if we're still connected
  // and make sure there aren't a bunch
  // of send failures
  // GO! txfailures keeps tracks of # of failures sending actual GPS and GSMLOC data (every time a send is successful the counter will reset)
  // So, here it means that if TCP is still connected (true), and the number of consecutive tx failures is < 3, no need to do mqtt.connect() again
  
  if(fona.TCPconnected() && txfailures < MAXTXFAILURES)
    return;

  Serial.println(F("Connecting to MQTT..."));

  int8_t ret, retries = 5;

  // once mqtt.connect() returns 0 while loop is done
  wdt_disable();
  while (retries && (ret = mqtt.connect()) != 0) {
    switch (ret) {
      // error cases
      case 1: Serial.println(F("Wrong protocol")); break;
      case 2: Serial.println(F("ID rejected")); break;
      case 3: Serial.println(F("Server unavail")); break;
      case 4: Serial.println(F("Bad user/pass")); break;
      case 5: Serial.println(F("Not authed")); break;
      case 6: Serial.println(F("Failed to subscribe")); break;
      default: Serial.println(F("Connection failed")); break;
    }
    Serial.println(F("Retrying MQTT connection"));
    wdt_reset();
    retries--;
    Serial.print(F("Retry MQTT remains:"));
    Serial.println(retries);
    delay(5000);
  } // GO! if mqtt.connect returns 0, the loop terminates at here

  wdt_enable(WDTO_8S);
  //if (retries == 0) halt("Resetting system");   // immediate reboot - actually should delay 10 minutes here too
  if (retries == 0) restIdle();   // immediate reboot - actually should delay 10 minutes here too
  Serial.println(F("MQTT Connected!"));
  txfailures = 0;
}

int embeddedCmd(char ch)
{
  switch  (smSlpTime)
  {
     case (0):
      if (ch=='<')  smSlpTime++;
        else  smSlpTime = 0;
      break;
     case (1):
      if (ch=='S')  smSlpTime++;
        else  smSlpTime = 0;
      break;
     case (2):
      if (ch=='=')  smSlpTime++;
        else  smSlpTime = 0;
      break;
     case (3):
      if (ch >= 0x30 && ch<= 0x39)
        {
        sleepTime += (ch-0x30)*100;
        smSlpTime++;
        }
      else
        smSlpTime = 0;
      break;
     case (4):
      if (ch >= 0x30 && ch<= 0x39)
        {
        sleepTime += (ch-0x30)*10;
        smSlpTime++;
        }
      else
        smSlpTime = 0;
      break;
     case (5):
      if (ch >= 0x30 && ch<= 0x39)
        {
        sleepTime += (ch-0x30);
        smSlpTime=0;
        }
      else
        smSlpTime = 0;
      break;
     default:
      break;
  }  
}

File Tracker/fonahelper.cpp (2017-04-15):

#include <SoftwareSerial.h>
#include "Adafruit_FONA.h"

#include <avr/wdt.h>                  // add this for watchdog function

#define halt(s) { Serial.println(F( s )); while(1);  }

extern Adafruit_FONA fona;
extern SoftwareSerial fonaSS;

boolean FONAconnect(const __FlashStringHelper *apn, const __FlashStringHelper *username, const __FlashStringHelper *password) {

  int retry;

  wdt_enable(WDTO_8S);
  wdt_reset();

  Serial.println(F("Initializing FONA....(May take a few seconds)"));
  fonaSS.begin(4800);

  if (! fona.begin(fonaSS)) {
    Serial.println(F("Couldn't find FONA"));
    return false;
  }

  fonaSS.println("AT+CMEE=2");
  Serial.println(F("FONA is OK"));

  wdt_reset();
  Serial.println(F("Checking for network..."));

  // try to get valid reply for AT+CREG
  // here we modify the codes such that even there is no locked carrier we
  // still go back to sleep until another time, this is for power conservation
  // simple test, even without the SIM card, system should sleep
  // this effectively will retry until watchdog is activated - no good
  retry = 80;     // 40 times retry is like 8 seconds like before, changed to 80 on 20170219
  while ((fona.getNetworkStatus() != 1) && retry)
  {
   delay(200);
   wdt_reset();
   retry--;
  }
  if (!retry) return false;
  
  wdt_reset();
  fona.setGPRSNetworkSettings(apn, username, password);

  // GO!  add a delay here
  delay(4000);
  // GO! do not disable GPRS.
  //Serial.println(F("Disabling GPRS"));
  //fona.enableGPRS(false);

  wdt_reset();

  Serial.println(F("Enabling GPRS"));
  // GO! we want to do it our way: turn ON GPRS and then delay for a while
  Serial.println(F("GO! enable GPRS now and then delay!"));
  int ret = fona.enableGPRS(true);
  delay(2000);
  wdt_reset();
  delay(2000);
  wdt_reset();
  delay(2000);
  wdt_reset();
  delay(2000);
  wdt_reset();
  Serial.println(F("GO! our delay is done. Is the Blue LED flashing rapidly?"));
  
  if (!ret) {
    Serial.println(F("Failed to turn GPRS on"));
    return false;
  }
  wdt_reset();

  return true;

}

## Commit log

2017-04-16 PCB Previews
2017-04-21 PCB files
    Designed by Michael CY Cheng mic.cycheng@gmail.com
    [BoardOutline.gbr, Bottom.gbr, BottomAssy.gbr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]
2017-04-21 Adding screenshot of PCB
2017-06-14 drifter.js to visualize the data collected from schools. Device_50009.gpx is an example of the data collected. This file is generated by getting the data from our MySQL database with the help of gps.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
2017-06-16 Added time file for storing the latest time of update of .gpx files. Python script now runs for all unique Device IDs and fetches the most recent data according to the time in file
2017-06-18 genjs.py now has a run() function. Imported genjs in gps.py, run() used to execute genjs when new device gpx created. used os.environ['tz'] to set timezone to HKT for time file
2017-06-28 Added new devices to ignore in gps.py. Also added >10 instead of >0 for lat,long. try,except in genjs.py so that drifter.html is always produced
2017-07-08 gps.py - added school names, binded drifter ID with their tracks by adding metadata in gpx files. genjs.py - to increase the default range of the timeline, added 50001 before all devices by creating 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
2017-07-08 Using bootstrap for better responsiveness on mobile as well as desktops. Changed styling and baselayers. Added scrollbar for choosing the devices on the map
2017-07-08 Simplebox.js for popup of the image of the WWF-Drifter-Device
2017-07-09 Updated leaflet timedimension options. Fit the time range to Device_50001. Defualt end date on calendar according to Date.now()
2017-07-12 Added Twitter Cards, Tweet button and Google Analytics. Added padding, keywords and author.
2017-07-12 Modified gps.py to exclude more devices, include 2nd dB. Added g+1 button to drifter.html, needs repositionaning. robots.txt for SEO exclude folders
2017-07-13 Reposition G+ button
2017-08-08 Added favicon, updated social buttons
